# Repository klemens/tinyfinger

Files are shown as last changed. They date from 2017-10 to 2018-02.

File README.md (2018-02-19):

# TinyFinger

TinyFinger is a small device powered by an ATtiny45 to produce pseudorandom
numbers for selecting student groups during the computer science hardware
courses at Leipzig University.

## board

The board is designed in KiCad and uses a single sided pcb layout using
mostly SMD components. The routing was done manually.

## code

The firmware for the ATtiny is written as an Arduino sketch using the
[ATTinyCore] board definitions. It uses a [linear congruential generator]
for generating pseudorandom numbers and transforms them to the needed
range using the gcc uniform_int_dist c++std implementation.

Flashing the firmware can be done using a normal Arduino programmes as an
ISP with the ArduinoISP example sketch included with the IDE. The PINs on
the board are from left to right: GND, MISO, VCC, SCK, MOSI, RESET.

## case

The case is modelled in Blender and intended for 3d printing, e.g. using
Cura after exporting the model as an stl file.

[ATTinyCore]: https://github.com/SpenceKonde/ATTinyCore
[linear congruential generator]: https://en.wikipedia.org/wiki/Linear_congruential_generator

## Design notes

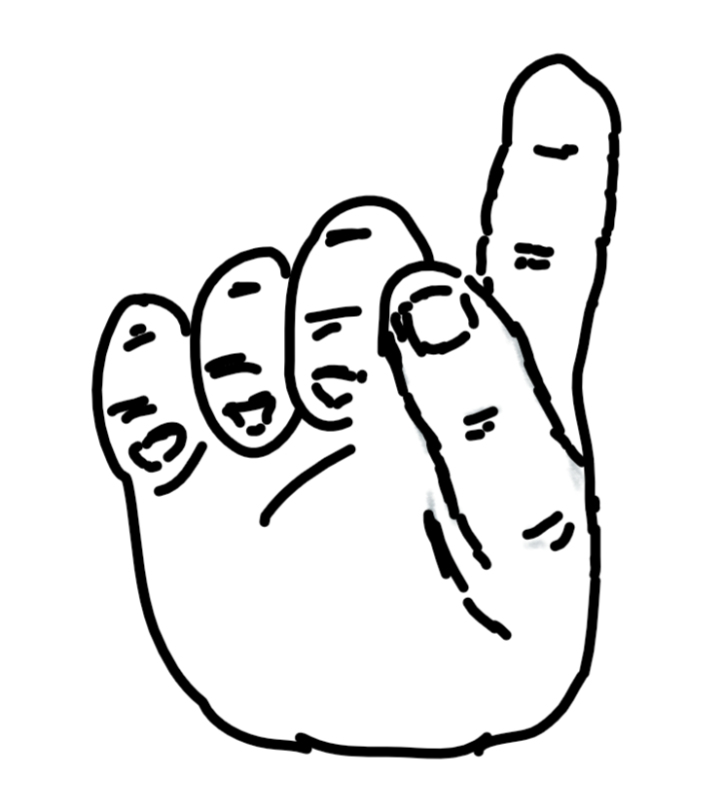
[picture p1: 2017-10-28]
artwork/tinyfinger.png

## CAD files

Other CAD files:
case/tiny_finger.blend

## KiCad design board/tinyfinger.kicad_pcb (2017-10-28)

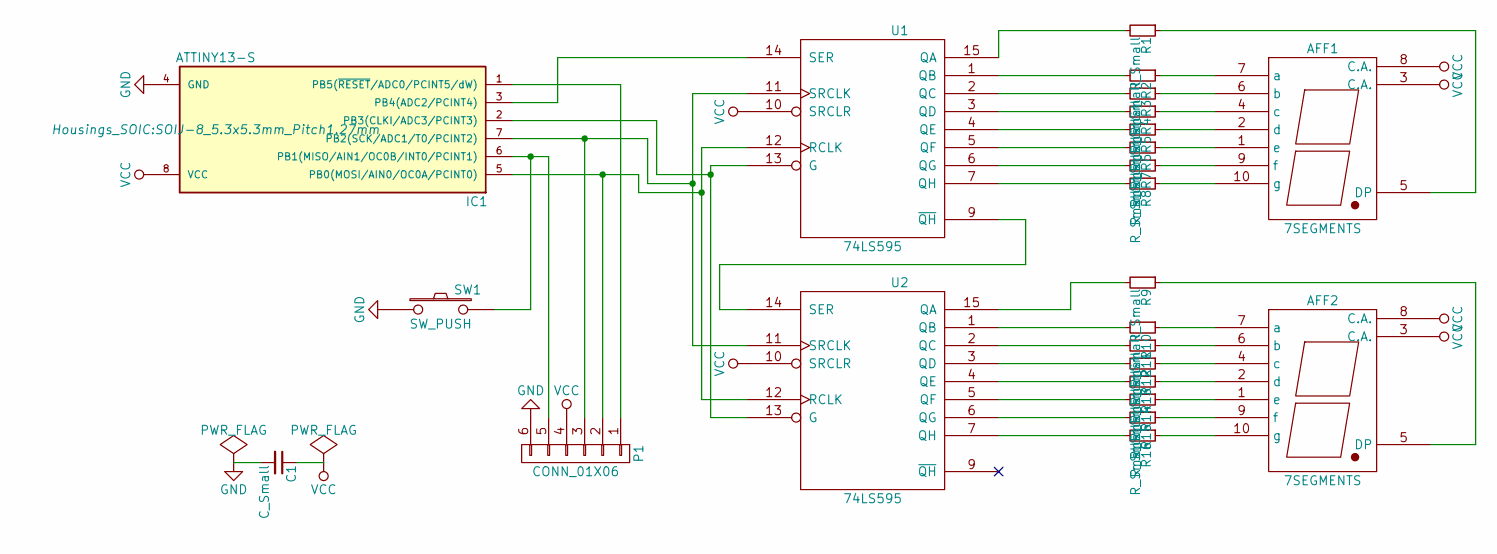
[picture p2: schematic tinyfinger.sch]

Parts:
AFF1, AFF2: 7SEGMENTS; 7SegmentLED_LTS6760_LTS6780
C1: C_Small; C_0805_HandSoldering
IC1: ATTINY13-S; SOIJ-8_5.3x5.3mm_Pitch1.27mm
P1: CONN_01X06; Pin_Header_Angled_1x06
R1, R2, R3, R4, R5, R6, R7, R8, R9, R10, R11, R12, R13, R14, R15, R16: R_Small; R_0805_HandSoldering
SW1: SW_PUSH; Switch_Shadow_Legostyle
U1, U2: 74LS595; DIP-16_W7.62mm_LongPads

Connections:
unnamed: AFF1.1 (e), R6.1
unnamed: AFF1.2 (d), R5.1
unnamed: AFF1.4 (c), R4.1
unnamed: AFF1.5 (DP), R1.1
unnamed: AFF1.6 (b), R3.1
unnamed: AFF1.7 (a), R2.1
unnamed: AFF1.9 (f), R7.1
unnamed: AFF1.10 (g), R8.1
unnamed: AFF2.1 (e), R14.1
unnamed: AFF2.2 (d), R13.1
unnamed: AFF2.4 (c), R12.1
unnamed: AFF2.5 (DP), R9.1
unnamed: AFF2.6 (b), R11.1
unnamed: AFF2.7 (a), R10.1
unnamed: AFF2.9 (f), R15.1
unnamed: AFF2.10 (g), R16.1
unnamed: IC1.1 (PB5(~RESET~/ADC0/PCINT5/dW)), P1.1
unnamed: IC1.2 (PB3(CLKI/ADC3/PCINT3)), U1.13 (G), U2.13 (G)
unnamed: IC1.3 (PB4(ADC2/PCINT4)), U1.14 (SER)
unnamed: IC1.5 (PB0(MOSI/AIN0/OC0A/PCINT0)), P1.2, U1.12 (RCLK), U2.12 (RCLK)
unnamed: IC1.7 (PB2(SCK/ADC1/T0/PCINT2)), P1.3, U1.11 (SRCLK), U2.11 (SRCLK)
unnamed: R1.2, U1.15 (QA)
unnamed: R2.2, U1.1 (QB)
unnamed: R3.2, U1.2 (QC)
unnamed: R4.2, U1.3 (QD)
unnamed: R5.2, U1.4 (QE)
unnamed: R6.2, U1.5 (QF)
unnamed: R7.2, U1.6 (QG)
unnamed: R8.2, U1.7 (QH)
unnamed: R9.2, U2.15 (QA)
unnamed: R10.2, U2.1 (QB)
unnamed: R11.2, U2.2 (QC)
unnamed: R12.2, U2.3 (QD)
unnamed: R13.2, U2.4 (QE)
unnamed: R14.2, U2.5 (QF)
unnamed: R15.2, U2.6 (QG)
unnamed: R16.2, U2.7 (QH)
unnamed: U1.9 (~QH), U2.14 (SER)
VCC: AFF1.3 (C.A.), AFF1.8 (C.A.), AFF2.3 (C.A.), AFF2.8 (C.A.), C1.1, IC1.8 (VCC), P1.4, U1.10 (SRCLR), U1.16 (VCC), U2.10 (SRCLR), U2.16 (VCC)

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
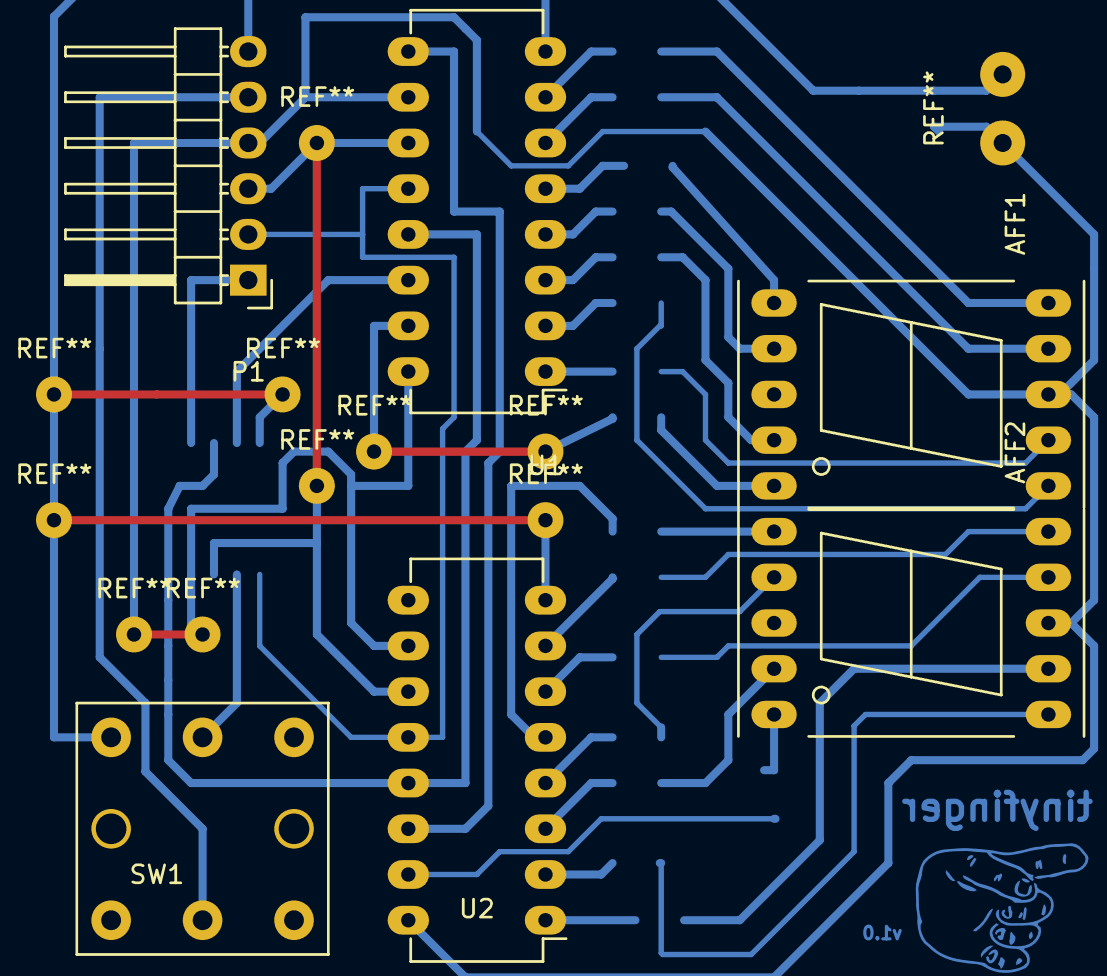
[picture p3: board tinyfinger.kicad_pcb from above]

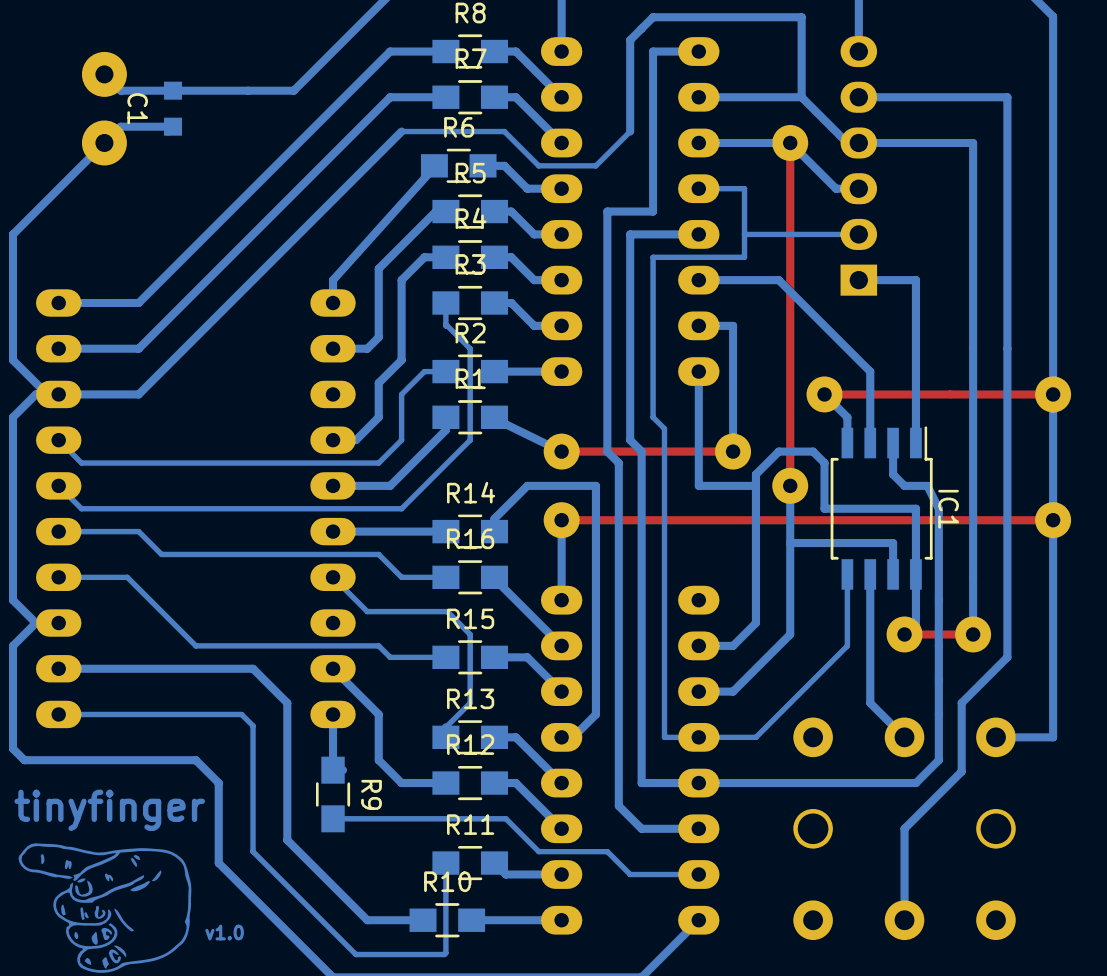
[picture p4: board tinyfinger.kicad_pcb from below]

Board: 2 copper layers, 25 parts (19 on the bottom side), 41 nets.

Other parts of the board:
svg2mod: G***; tinyfinger

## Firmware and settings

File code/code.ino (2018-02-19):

// Conflicts with std c++ headers
#undef min
#undef max

#include "button.h"
#include "debounce.h"
#include "lcg_rng.h"
#include "segment.h"
#include "uniform_int_dist.h"


#define BUTTON_PIN 1
#define DISPLAY_ENABLE 3

lcg_rng rng;
std::uniform_int_distribution<uint8_t> distribution(1,16);

SegmentDisplay<4, 2, 0> display;

using MainButton = Button<150, 150>;

Debounce<20> debounce;
MainButton button;

bool activeGroups[16] = { false };
uint8_t activeCount = 0;

#define NUM_SLOWDOWN 12
const uint16_t PROGMEM SLOWDOWN[NUM_SLOWDOWN] = {
    35, 32,
    20, 64,
     8, 125,
     4, 250,
     2, 500,
     2, 1000
};

void setup() {
    pinMode(BUTTON_PIN, INPUT_PULLUP);

    pinMode(DISPLAY_ENABLE, OUTPUT);
    digitalWrite(DISPLAY_ENABLE, 0);

    display.setDash();
    display.write();

    resetGroups();
}

enum class State : uint8_t {
    Sleep,
    Idle,
    Menu,
    Counting,
    Slowing
};

auto state = State::Idle;
uint16_t timeout;

void loop() {
    rng();

    bool buttonPressed = !digitalRead(PIN1);
    auto event = button.event(debounce.event(buttonPressed));

    switch(state) {
        case State::Sleep:
            if(buttonPressed) {
                digitalWrite(DISPLAY_ENABLE, 0);
                state = State::Idle;
                timeout = millis();
            }
        case State::Idle:
            if(event == ButtonEvent::Press) {
                state = State::Slowing;
            } else if(event == ButtonEvent::LongPress) {
                state = State::Counting;
                timeout = millis();
            } else if(event == ButtonEvent::DoublePress) {
                state = State::Menu;
            } else if((uint16_t) millis() - timeout >= 10000) {
                digitalWrite(DISPLAY_ENABLE, 1);
                state = State::Sleep;
            }
            break;
        case State::Menu:
            displayMenu();
            display.setDash();
            display.write();
            state = State::Idle;
            timeout = millis();
            break;
        case State::Counting:
            if(event == ButtonEvent::LongPress) {
                // stay in this state
                if((uint16_t) millis() - timeout >= 25) {
                    display.set(generateNextNumber());
                    display.write();
                    timeout = millis();
                }
            } else {
                state = State::Slowing;
            }
            break;
        case State::Slowing:
            slowdown();
            state = State::Idle;
            timeout = millis();
            break;
    }
}

uint8_t generateNextNumber() {
    uint8_t randomNumber = distribution(rng);

    uint8_t i;
    for(i = 0; i < 16 && randomNumber != 0; i += 1) {
        if(activeGroups[i]) {
            randomNumber -= 1;
        }
    }

    // already offset by 1 because of the loop postincrement
    return i;
}

void slowdown() {
    uint8_t currentNumber;

    for(size_t i = 0; i < NUM_SLOWDOWN; i += 2) {
        for(size_t j = 0; j < pgm_read_word_near(SLOWDOWN + i); ++j) {
            currentNumber = generateNextNumber();
            display.set(currentNumber);
            display.write();
            delay(pgm_read_word_near(SLOWDOWN + i + 1));
        }
    }

    for(uint8_t i = 0; i < 2; ++i) {
        display.setOff();
        display.write();
        delay(250);
        display.set(currentNumber);
        display.write();
        delay(250);
    }
}

void resetGroups() {
    for(uint8_t i = 0; i < 16; i += 1) {
        activeGroups[i] = true;
        activeCount += 1;
    }
}

void displayMenu() {
    uint8_t currentGroup = 0;
    uint16_t timeout = millis();

    constexpr uint16_t longPressDelay = 300;
    Button<longPressDelay, 150> menuButton;

    for(;;) {
        bool buttonPressed = !digitalRead(PIN1);
        auto event = menuButton.event(debounce.event(buttonPressed));

        display.set(currentGroup + 1);
        display.setDP(activeGroups[currentGroup]);
        display.write();

        switch(event) {
            case ButtonEvent::LongPress:
                // rotate through groups
                if((uint16_t) millis() - timeout >= longPressDelay) {
                    currentGroup = (currentGroup + 1) % 16;
                    timeout = millis();
                }
                break;
            case ButtonEvent::Press:
                // (de)activate group
                activeGroups[currentGroup] = !activeGroups[currentGroup];
                break;
            case ButtonEvent::DoublePress:
                // exit menu
                activeCount = 0;
                for(uint8_t i = 0; i < 16; i += 1) {
                    activeCount += (uint8_t) activeGroups[i];
                }
                if(activeCount == 0) {
                    resetGroups();
                }

                distribution = std::uniform_int_distribution<uint8_t>(1,activeCount);
                return;
        }
    }
}

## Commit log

2017-10-28 Import the kicad project for the board and related artwork
    [tinyfinger.kicad_pcb, tinyfinger.sch]
2017-10-28 Import the blender project for the case
    [tiny_finger.blend]
2017-10-28 Import the arduino sketch for the random number generation
2017-11-06 Almost complete the case (rc1)
    [tiny_finger.blend]
2017-11-09 Fix case battery height and add space for a mounting hole
    [tiny_finger.blend]
2017-11-10 Add tinyfinger relief to the case
    [tiny_finger.blend]
2017-11-17 Implement a slowing countdown on button request
2017-11-17 Add state machines for recognizing different button presses
    For now single, double and long presses are supported.
2017-11-30 Use the state machines to control the finger
    Fixes uint16_t comparisons with millis(), removes DoublePressed state
    in button.h.
    [code.ino]
2017-12-01 Update README
    Switch to an ATtiny45 and the ATTinyCore.
2018-02-19 Disable led display after 10 seconds to save energy
    Going to sleep and waking on an interrupt generated by the button would
    save even more energy, but it our current chip unfortunately has problems
    waking up reliably.
    [code.ino]
2018-02-19 Document PIN-order in the README
